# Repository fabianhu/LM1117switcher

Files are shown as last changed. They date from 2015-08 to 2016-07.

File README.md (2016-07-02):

# LM1117switcher
SOT-223 step down voltage regulator to replace LM1117-3.3 with a higher efficiency solution without redesigning the base board.
It fits directly onto the SOT223 Footprint of the LM1117.

Order the board at https://oshpark.com/shared_projects/o3DHlL3n

...here shown on top of a [ESPRGBLED board](https://github.com/fabianhu/ESPRGBLED)
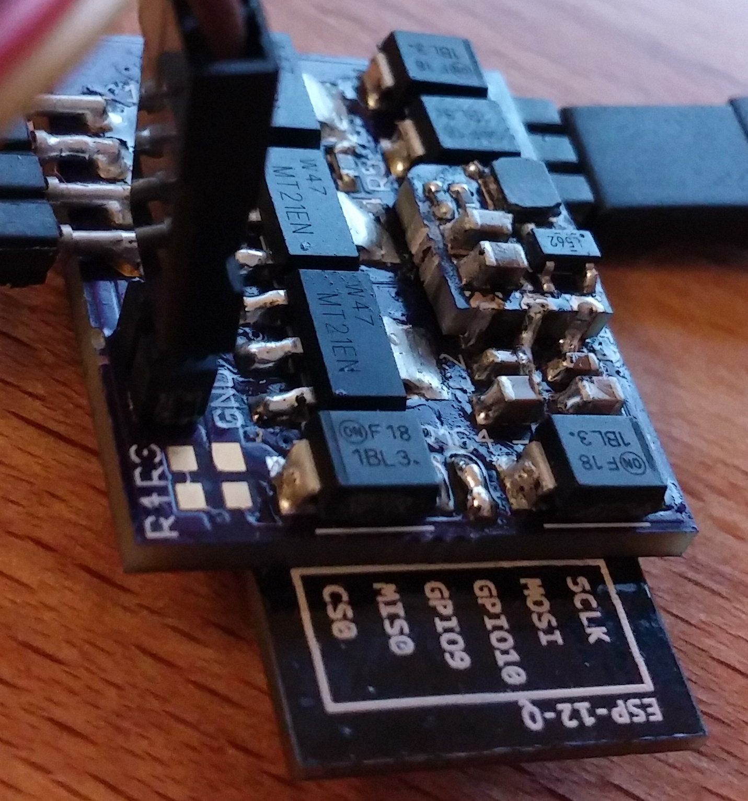
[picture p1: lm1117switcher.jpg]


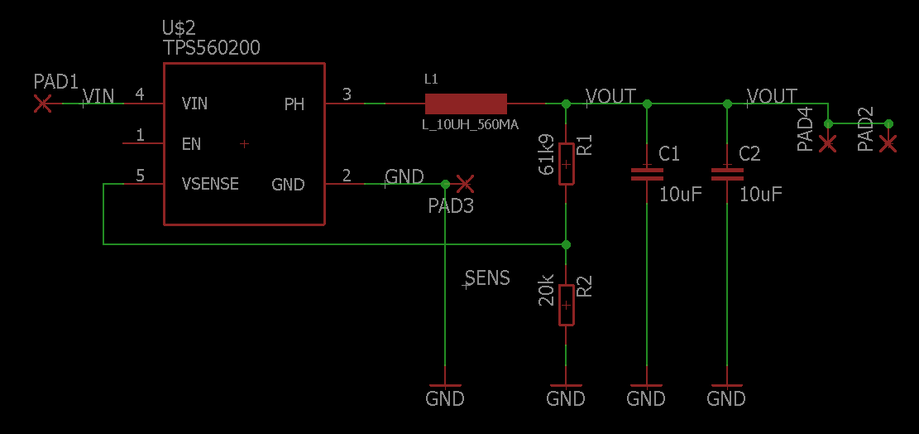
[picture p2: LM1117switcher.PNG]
schematic

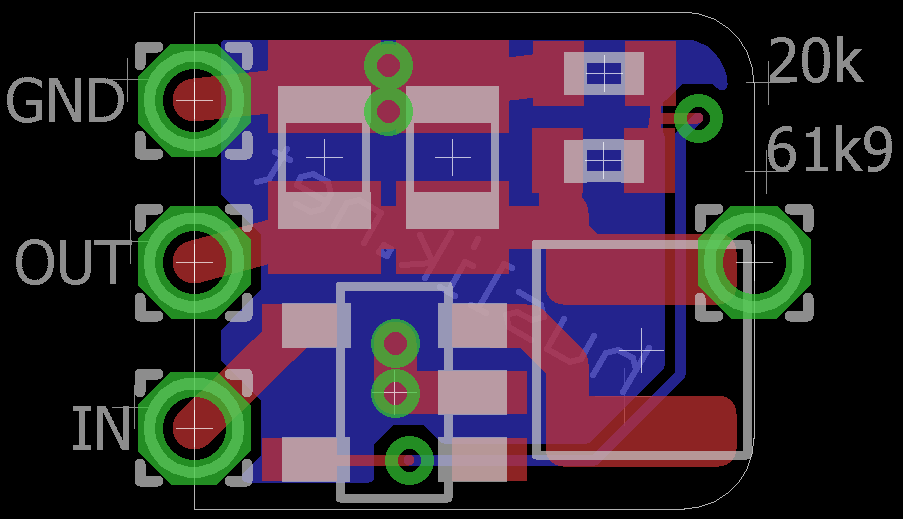
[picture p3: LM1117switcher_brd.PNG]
board


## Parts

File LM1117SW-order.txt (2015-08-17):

Order list for D:/projekt/work/#Github/ESPRGBLED/LM1117SW.sch
Exported from EAGLE with DesignLink

Anzahl	Value	Package	Ordercode	Hersteller	Herstellercode	Verfügbarkeit	Preis (ab)	Beschreibung
30	10uF	C0805K	2320833	MULTICOMP	MC0805X106K250CT	36764	0.066	MULTICOMP - MC0805X106K250CT - KONDENSATOR, MLCC, X5R, 10UF, 25V, 0805
15	L_10UH_560MA	TYS3010100M-10	2292503	LAIRD TECHNOLOGIES	TYS3010100M-10	3718	0.167	LAIRD TECHNOLOGIES - TYS3010100M-10 - INDUKTIVITÄT, 10µH, SMD
60		1,6/0,9	unknown					
15	61k9	R0402	1803730	MULTICOMP	MC00625W0402161K9	27932	0.0016	MULTICOMP - MC00625W0402161K9 - WIDERSTAND, 61K9, 0.063W, 1%, 0402
15	20k	R0402	1469693	VISHAY DRALORIC	CRCW040220K0FKED	41859	0.0034	VISHAY DRALORIC - CRCW040220K0FKED - WIDERSTAND, 0402, 20K0, 1%
15	TPS560200	SOT23-5	2373566	TEXAS INSTRUMENTS	TPS560200DBVT	3086	0.559	TEXAS INSTRUMENTS - TPS560200DBVT - IC, DC/DC-WANDLER, 650KHZ, SOT23-5

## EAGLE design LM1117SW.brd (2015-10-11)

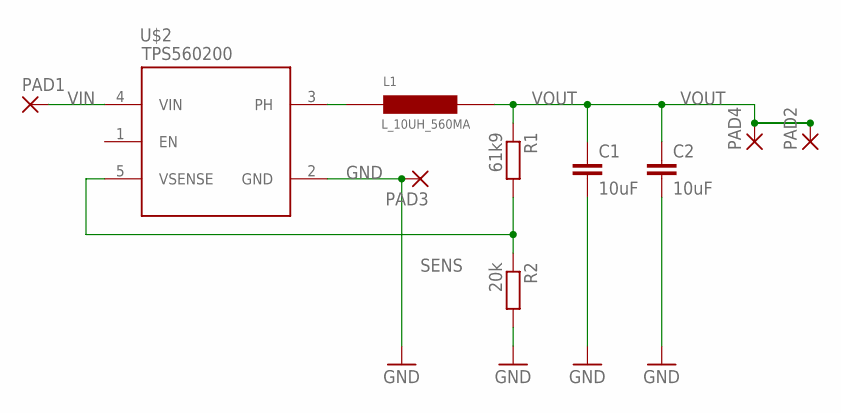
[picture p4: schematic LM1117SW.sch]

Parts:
C1, C2: 10uF; C0805K; MPN MC0805X106K250CT
L1: L_10UH_560MA; TYS3010100M-10; MPN TYS3010100M-10
PAD1, PAD2, PAD3, PAD4: 1,6/0,9
R1: 61k9; R0402; MPN MC00625W0402161K9
R2: 20k; R0402; MPN CRCW040220K0FKED
U$2: TPS560200; SOT23-5; MPN TPS560200DBVT

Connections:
GND: C1.2, C2.2, PAD3.1, R2.2, U$2.2 (GND)
unnamed: L1.P$1, U$2.3 (PH)
SENS: R1.2, R2.1, U$2.5 (VSENSE)
VIN: PAD1.1, U$2.4 (VIN)
VOUT: C1.1, C2.1, L1.P$2, PAD2.1, PAD4.1, R1.1

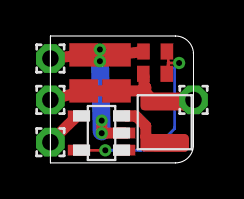
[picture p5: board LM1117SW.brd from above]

Board: 2 copper layers, 8.0 x 7.0 mm, 10 parts (0 on the bottom side), 5 nets.

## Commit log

2015-08-17 ordered HW
    [LM1117SW.brd, LM1117SW.sch]
2015-09-27 minor layout optimisation
    better soldering of inductor
    [LM1117SW.brd, LM1117SW.sch]
2015-09-27 added images
    [LM1117SW.brd, LM1117SW.sch]
2015-10-11 updated pad names
    [LM1117SW.brd]
